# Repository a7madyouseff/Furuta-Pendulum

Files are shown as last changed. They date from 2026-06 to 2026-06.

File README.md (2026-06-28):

# Furuta-Pendulum
# Fixed-Pivot Inverted Pendulum Control System

This project implements a fixed-pivot inverted pendulum system using an Arduino-based control setup. The goal is to balance a freely rotating pendulum in the upright position by controlling the motion of a DC motor arm.

The system uses a DC motor with an encoder to measure the arm position and an AS5600 magnetic encoder to measure the pendulum angle. A feedback controller is implemented on an Arduino to stabilize the pendulum around the upright equilibrium point.

## Project Overview

The inverted pendulum is a classic unstable control system. Without control, the pendulum naturally falls due to gravity. In this project, the controller continuously measures the pendulum angle and moves the motor arm to correct the pendulum motion and keep it balanced.

The project includes:

- Mechanical design of the pendulum and motor arm
- Sensor integration using motor encoder and AS5600 magnetic encoder
- Arduino-based real-time control
- Motor driving using the L298N motor driver
- Controller tuning and testing
- MATLAB analysis of system response

## Hardware Used

- Arduino UNO
- DC motor with built-in encoder
- L298N motor driver
- AS5600 magnetic angle sensor
- 12 V external motor power supply
- 5 V logic supply
- 3D-printed motor arm and pendulum parts
- Bearing-supported pendulum pivot
- Permanent magnet for AS5600 sensing

## Wiring Summary

### Motor Driver L298N

| L298N Pin | Arduino / Supply |
|---|---|
| IN1 | D7 |
| IN2 | D8 |
| ENA | D9 PWM |
| GND | Common GND |
| VCC | 12 V motor supply |
| 5V | 5 V logic |
| OUT1 / OUT2 | DC motor terminals |

### Motor Encoder

| Encoder Pin | Arduino |
|---|---|
| VCC | 5 V |
| GND | GND |
| Channel A | D2 interrupt |
| Channel B | D4 |

### AS5600 Magnetic Encoder

| AS5600 Pin | Arduino |
|---|---|
| VCC | 5 V |
| GND | GND |
| SDA | A4 |
| SCL | A5 |

## Control Method

The controller is implemented in Arduino code using feedback from the pendulum angle. The best experimental performance was achieved using a PD controller.

The controller calculates the pendulum angle error and angular velocity, then generates a PWM signal for the motor driver. The motor direction is adjusted depending on the required correction direction.

Main control parameters:

```cpp
float Kp = 11.0;
float Kd = 1.3;
float Ki = 0.0;

int minPWM = 40;
int maxPWM = 230;

float deadband = 1.2;
float activeAngleLimit = 30.0;
int MOTOR_SIGN = -1;

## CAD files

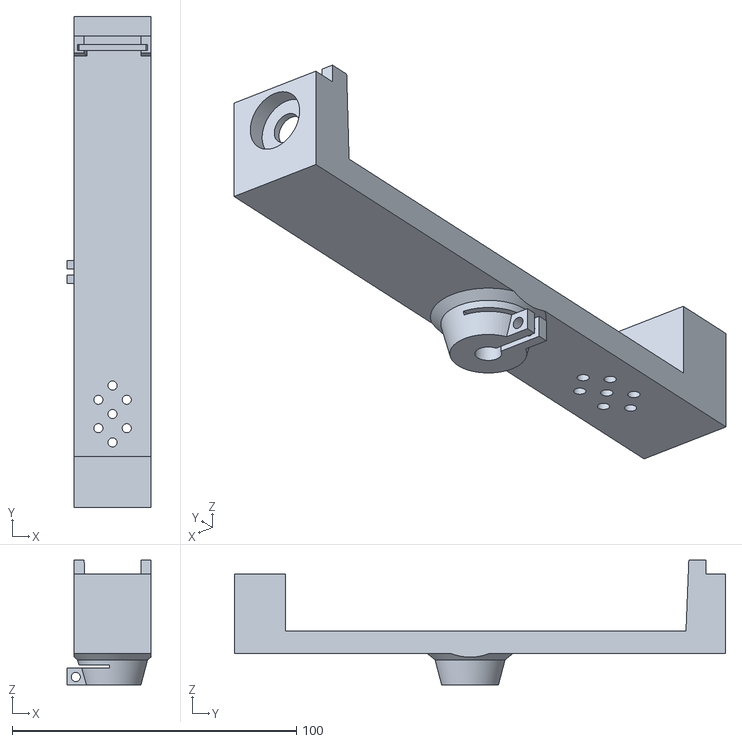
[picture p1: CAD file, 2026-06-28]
CAD_MODLES/arm.stl
29.5 x 173.0 x 44.0

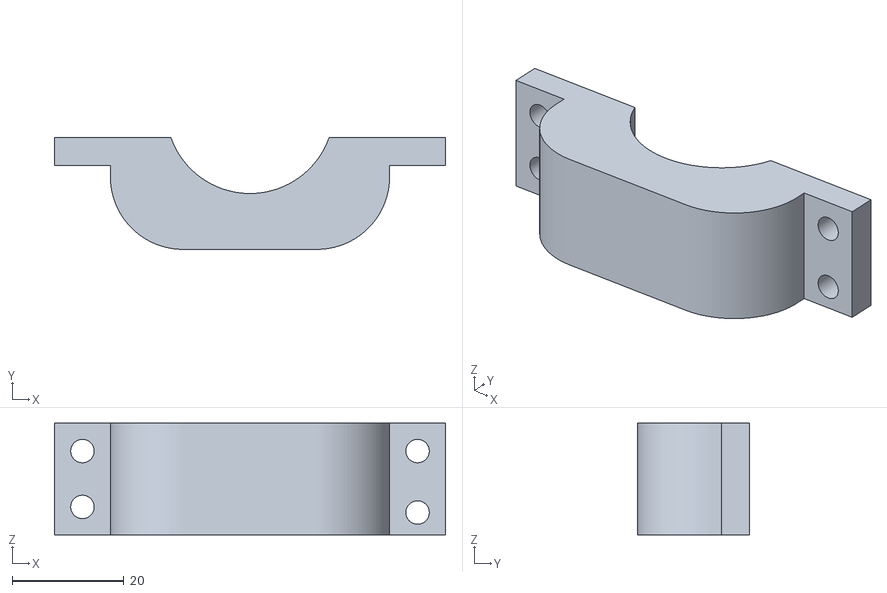
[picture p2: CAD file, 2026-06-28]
CAD_MODLES/MotorClip2.stl
70.0 x 20.0 x 20.0

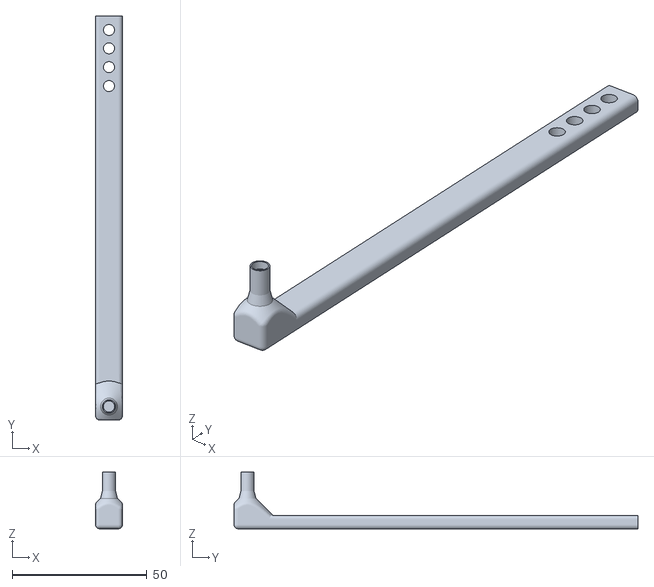
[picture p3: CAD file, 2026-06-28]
CAD_MODLES/Pemdulum.stl
10.0 x 150.0 x 21.0

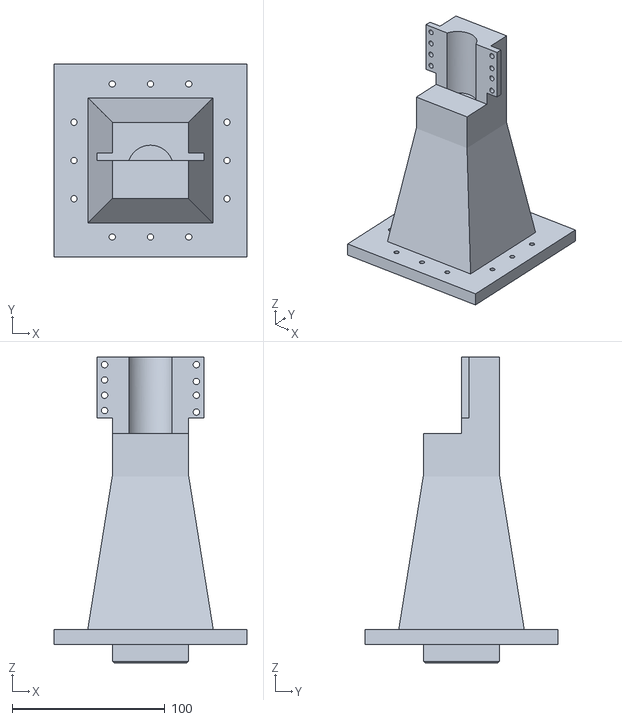
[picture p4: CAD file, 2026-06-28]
CAD_MODLES/MotorMount.stl
126.0 x 126.0 x 200.0

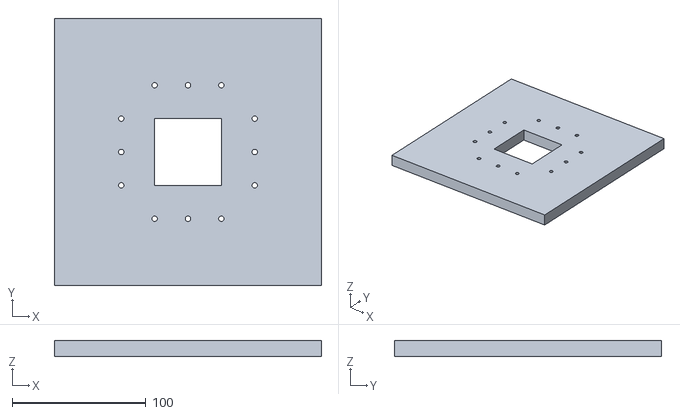
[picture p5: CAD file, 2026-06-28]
CAD_MODLES/Base.stl
200.0 x 200.0 x 12.0

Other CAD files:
CAD_MODLES/MotorClip1.stl

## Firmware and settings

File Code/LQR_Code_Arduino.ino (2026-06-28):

// ============================================
// FURUTA PENDULUM - LQR Balancing Controller
// Motor encoder (alpha) + AS5600 (beta)
// Arduino Uno
// ============================================

#include <Wire.h>

// ----- Motor Driver Pins -----
#define IN1 7
#define IN2 8
#define ENA 9

// ----- Motor Encoder Pins (arm angle alpha) -----
#define MOTOR_ENC_A 2
#define MOTOR_ENC_B 3

// ----- AS5600 Magnetic Encoder (pendulum angle beta) -----
#define AS5600_ADDR 0x36
#define RAW_ANGLE_H 0x0C

// ----- LQR Gains (from MATLAB) -----
// u = -K*x  where x = [alpha, beta, alpha_dot, beta_dot]
float K1 = -1;    // alpha gain
float K2 = -33.2177;   // beta gain (most important)
float K3 = -1.4179;    // alpha_dot gain
float K4 = -6.8072;    // beta_dot gain

// ----- Variables -----
volatile long motorCount = 0;
int MOTOR_PPR = 360;

float alpha = 0, beta = 0;
float alpha_prev = 0, beta_prev = 0;
float alpha_dot = 0, beta_dot = 0;

float beta_offset = 0;  // calibration offset
unsigned long lastTime = 0;
float dt = 0.01;  // 10ms loop

// ----- AS5600 read function -----
float readBeta() {
  Wire.beginTransmission(AS5600_ADDR);
  Wire.write(RAW_ANGLE_H);
  Wire.endTransmission();
  Wire.requestFrom(AS5600_ADDR, 2);
  int highByte = Wire.read();
  int lowByte = Wire.read();
  int rawAngle = (highByte << 8) | lowByte;
  float angleDeg = (rawAngle / 4096.0) * 360.0;
  return angleDeg;
}

void setup() {
  Serial.begin(9600);
  Wire.begin();
  
  // Motor pins
  pinMode(IN1, OUTPUT);
  pinMode(IN2, OUTPUT);
  pinMode(ENA, OUTPUT);
  
  // Motor encoder
  pinMode(MOTOR_ENC_A, INPUT_PULLUP);
  pinMode(MOTOR_ENC_B, INPUT_PULLUP);
  attachInterrupt(digitalPinToInterrupt(MOTOR_ENC_A), readMotorEncoder, RISING);
  
  // Calibrate beta to upright = 0
  delay(500);
  beta_offset = readBeta();
  
  lastTime = millis();
}

void loop() {
  // Timing
  unsigned long now = millis();
  dt = (now - lastTime) / 1000.0;
  if (dt < 0.01) return;  // run at 100Hz
  lastTime = now;
  
  // ----- Read states -----
  alpha = (motorCount / (float)MOTOR_PPR) * 360.0; // degrees
  beta = readBeta() - beta_offset;                  // degrees from upright
  
  // Convert to radians for control
  float alpha_rad = alpha * PI / 180.0;
  float beta_rad = beta * PI / 180.0;
  
  // ----- Compute velocities -----
  alpha_dot = (alpha_rad - alpha_prev) / dt;
  beta_dot = (beta_rad - beta_prev) / dt;
  alpha_prev = alpha_rad;
  beta_prev = beta_rad;
  
  // ----- LQR Control Law: u = -Kx -----
  float u = -(K1*alpha_rad + K2*beta_rad + K3*alpha_dot + K4*beta_dot);
  
  // ----- Apply control to motor -----
  applyMotor(u);
  
  // ----- Send data to Serial -----
  Serial.print(now/1000.0);
  Serial.print(",");
  Serial.print(alpha);
  Serial.print(",");
  Serial.println(beta);
}

void applyMotor(float u) {
  // Convert control signal to PWM
  int pwm = (int)abs(u);
  if (pwm > 255) pwm = 255;  // saturate
  
  // Safety: if pendulum fell too far, stop motor
  if (abs(beta) > 45) {
    analogWrite(ENA, 0);
    return;
  }
  
  // Set direction based on sign of u
  if (u > 0) {
    digitalWrite(IN1, HIGH);
    digitalWrite(IN2, LOW);
  } else {
    digitalWrite(IN1, LOW);
    digitalWrite(IN2, HIGH);
  }
  analogWrite(ENA, pwm);
}

void readMotorEncoder() {
  if (digitalRead(MOTOR_ENC_B) == HIGH) {
    motorCount++;
  } else {
    motorCount--;
  }
}
